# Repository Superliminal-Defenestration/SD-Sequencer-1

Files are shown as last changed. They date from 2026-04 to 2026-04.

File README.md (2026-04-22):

Drum machine / sequencer being developed in Kicad 8. Open source and free to use, based mainly on Roland TR808s, etc.
As simple as it gets--- nothing to produce fancy attack/decay envelopes on most stuff, mostly only fancy VCA envelopes for white-noise based sounds. This is meant to be as easy to understand and low-cost as possible.
I'll be writing in notes as I develop the system on what math I'm using to determine components :).

White noise generation with transistor breakdown accredited to Moritz Klein!

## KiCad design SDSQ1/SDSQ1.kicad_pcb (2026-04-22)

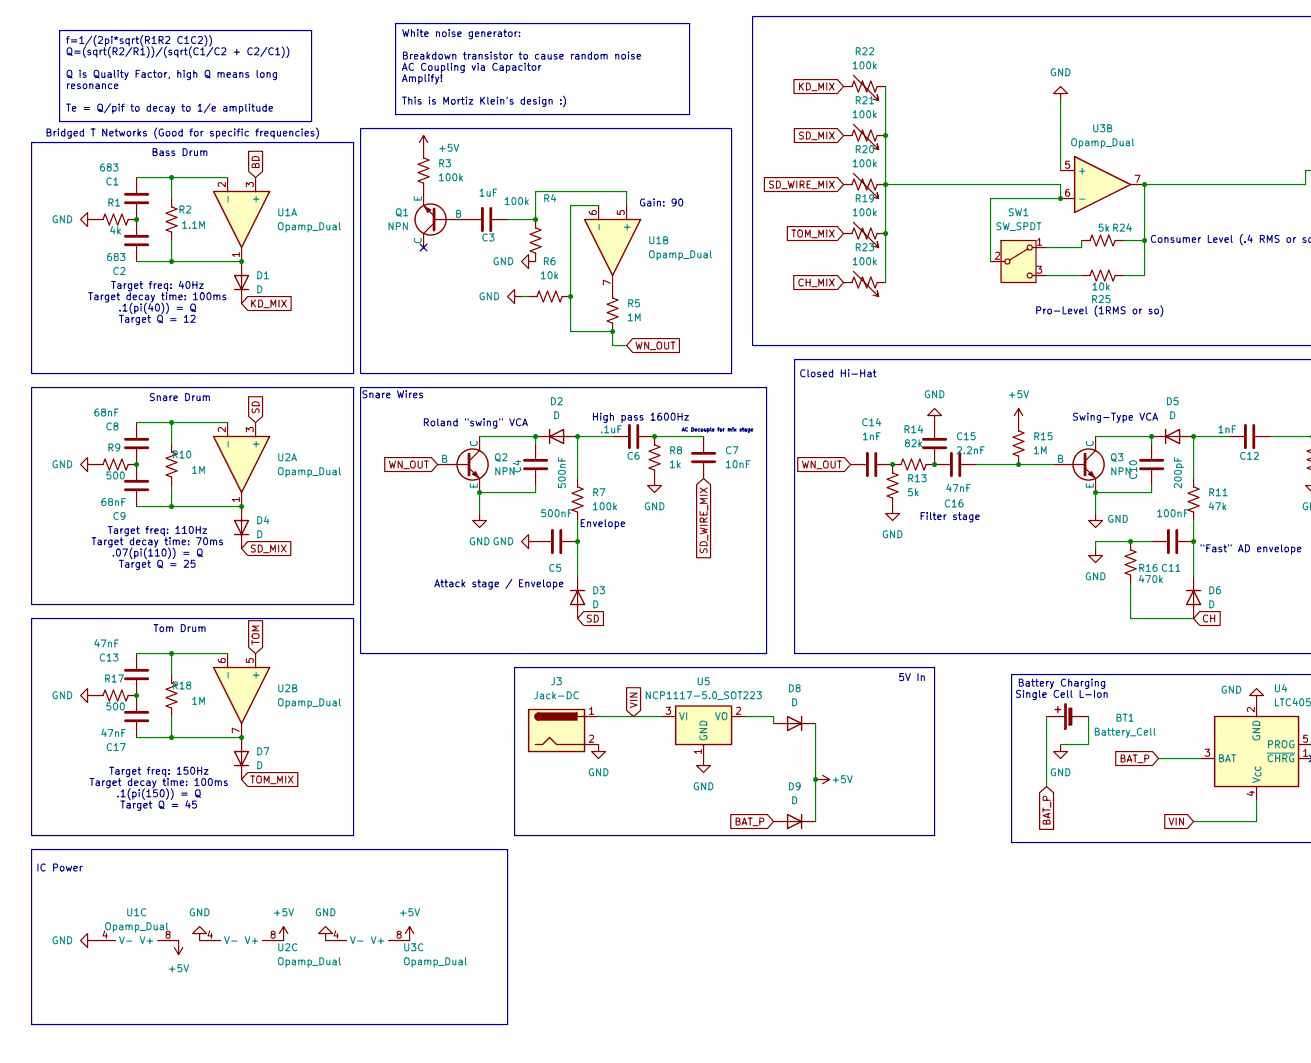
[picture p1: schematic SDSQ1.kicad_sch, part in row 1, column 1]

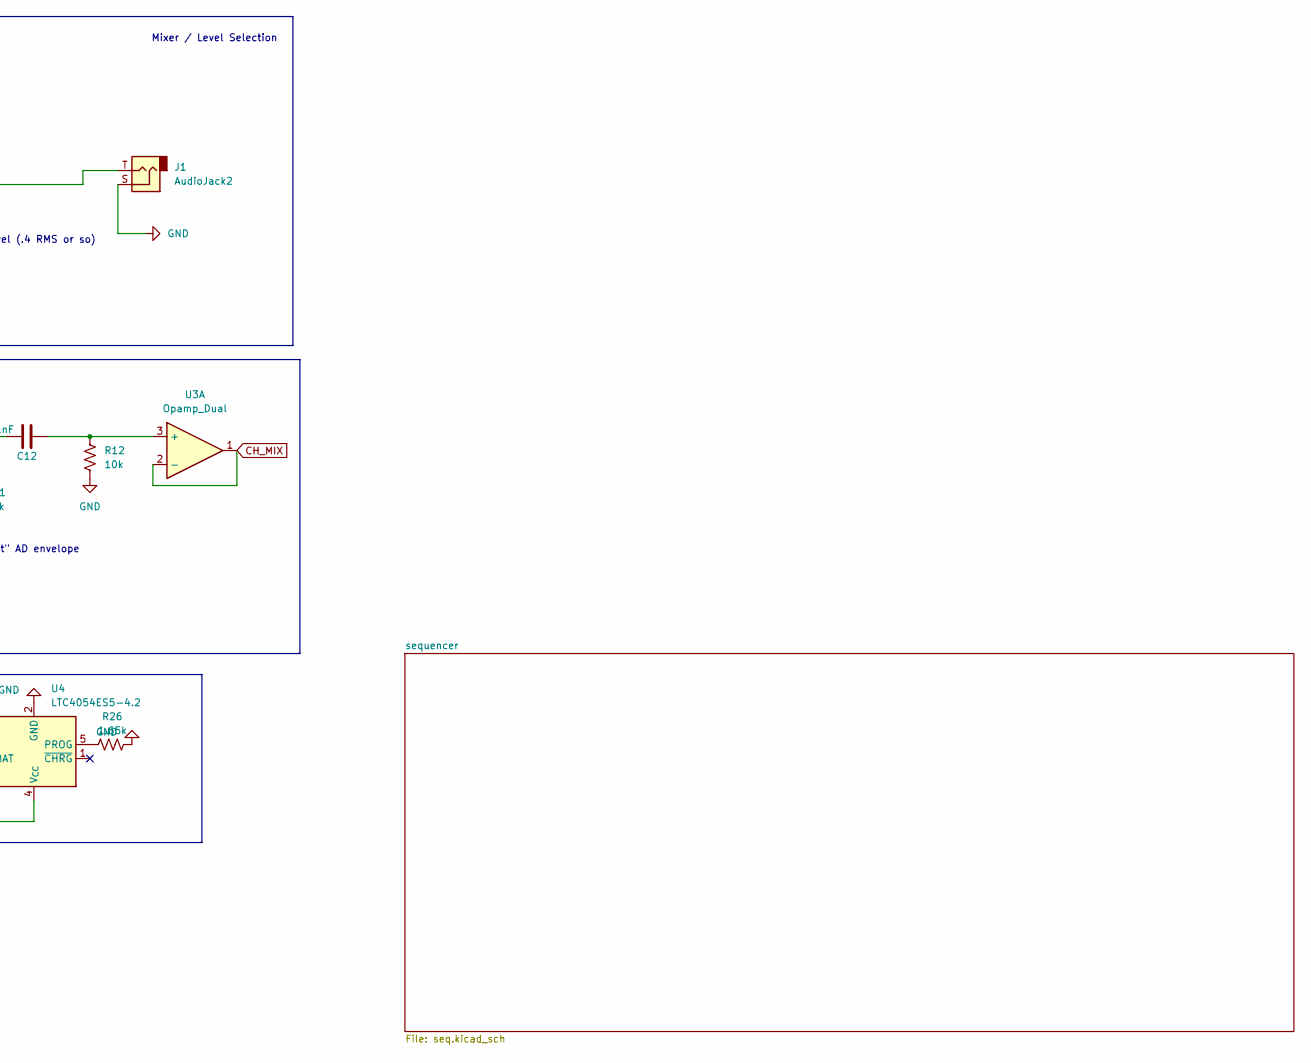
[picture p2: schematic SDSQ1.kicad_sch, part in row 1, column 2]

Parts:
BT1: Battery_Cell; BatteryHolder_Keystone_1042_1x18650
C1, C2: 683; C_Axial_L3.8mm_D2.6mm_P7.50mm_Horizontal
C3: 1uF; C_Axial_L3.8mm_D2.6mm_P7.50mm_Horizontal
C4, C5: 500nF; C_Axial_L3.8mm_D2.6mm_P7.50mm_Horizontal
C6: .1uF; C_Axial_L3.8mm_D2.6mm_P7.50mm_Horizontal
C7: 10nF; C_Axial_L3.8mm_D2.6mm_P7.50mm_Horizontal
C8, C9: 68nF; C_Axial_L3.8mm_D2.6mm_P7.50mm_Horizontal
C10: 200pF; C_Axial_L3.8mm_D2.6mm_P7.50mm_Horizontal
C11: 100nF; C_Axial_L3.8mm_D2.6mm_P7.50mm_Horizontal
C12, C14: 1nF; C_Axial_L3.8mm_D2.6mm_P7.50mm_Horizontal
C13, C16, C17: 47nF; C_Axial_L3.8mm_D2.6mm_P7.50mm_Horizontal
C15: 2.2nF; C_Axial_L3.8mm_D2.6mm_P7.50mm_Horizontal
D1, D2, D3, D4, D5, D6, D7, D8, D9: D; D_A-405_P7.62mm_Horizontal
J1: AudioJack2; Jack_3.5mm_PJ320E_Horizontal
J3: Jack-DC; BarrelJack_Horizontal
Q1, Q2, Q3: NPN; TO-92S
R1: 4k; R_Axial_DIN0204_L3.6mm_D1.6mm_P5.08mm_Vertical
R2: 1.1M; R_Axial_DIN0204_L3.6mm_D1.6mm_P5.08mm_Vertical
R3, R4, R7, R19, R20, R21, R22, R23: 100k; R_Axial_DIN0204_L3.6mm_D1.6mm_P5.08mm_Vertical
R5, R10, R15, R18: 1M; R_Axial_DIN0204_L3.6mm_D1.6mm_P5.08mm_Vertical
R6, R12, R25: 10k; R_Axial_DIN0204_L3.6mm_D1.6mm_P5.08mm_Vertical
R8: 1k; R_Axial_DIN0204_L3.6mm_D1.6mm_P5.08mm_Vertical
R9, R17: 500; R_Axial_DIN0204_L3.6mm_D1.6mm_P5.08mm_Vertical
R11: 47k; R_Axial_DIN0204_L3.6mm_D1.6mm_P5.08mm_Vertical
R13, R24: 5k; R_Axial_DIN0204_L3.6mm_D1.6mm_P5.08mm_Vertical
R14: 82k; R_Axial_DIN0204_L3.6mm_D1.6mm_P5.08mm_Vertical
R16: 470k; R_Axial_DIN0204_L3.6mm_D1.6mm_P5.08mm_Vertical
R26: 1.65k; R_Axial_DIN0204_L3.6mm_D1.6mm_P5.08mm_Vertical
SW1: SW_SPDT; SW_Push_1P2T_Vertical_E-Switch_800UDP8P1A1M6
U1, U2, U3: Opamp_Dual; DIP-8_W7.62mm_Socket
U4: LTC4054ES5-4.2; TSOT-23-5
U5: NCP1117-5.0_SOT223; SOT-223-3_TabPin2

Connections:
+5V: D8.1 (K), D9.1 (K), R3.1, R15.1, U1.8 (V+), U2.8 (V+), U3.8 (V+); also elsewhere on the board
BAT_P: BT1.1 (+), D9.2 (A), U4.3 (BAT)
BD: U1.3 (+); also elsewhere on the board
CH: D6.2 (A), R16.2; also elsewhere on the board
CH_MIX: R23.2, U3.1, U3.2 (-)
GND: BT1.2 (-), C4.2, C5.1, C10.2, C11.1, C15.2, J1.S, J3.2, Q2.3 (E), Q3.3 (E), R1.1, R4.2, R6.1, R8.2, R9.1, R12.2, R13.2, R16.1, R17.1, R26.2, U1.4 (V-), U2.4 (V-), U3.4 (V-), U3.5 (+), U4.2 (GND), U5.1 (GND); also elsewhere on the board
KD_MIX: D1.1 (K), R22.2
unnamed: C1.2, C2.1, R1.2
unnamed: C6.2, C7.2, R8.1
unnamed: C8.2, C9.1, R9.2
unnamed: C13.2, C17.1, R17.2
unnamed: C14.2, R13.1, R14.1
unnamed: C15.1, C16.2, R14.2
unnamed: C2.2, D1.2 (A), R2.1, U1.1
unnamed: C6.1, D2.2 (A), R7.1
unnamed: C4.1, D2.1 (K), Q2.1 (C)
unnamed: C5.2, D3.1 (K), R7.2
unnamed: C9.2, D4.2 (A), R10.1, U2.1
unnamed: C12.1, D5.2 (A), R11.1
unnamed: C10.1, D5.1 (K), Q3.1 (C)
unnamed: C11.2, D6.1 (K), R11.2
unnamed: C17.2, D7.2 (A), R18.1, U2.7
unnamed: D8.2 (A), U5.2 (VO)
unnamed: J1.T, R24.2, R25.2, U3.7
unnamed: C3.1, Q1.2 (B)
unnamed: Q1.3 (E), R3.2
unnamed: C16.1, Q3.2 (B), R15.2
unnamed: R5.1, U1.7
unnamed: R24.1, SW1.1 (A)
unnamed: R19.1, R20.1, R21.1, R22.1, R23.1, SW1.2 (B), U3.6 (-)
unnamed: R25.1, SW1.3 (C)
unnamed: C1.1, R2.2, U1.2 (-)
unnamed: C3.2, R4.1, U1.5 (+)
unnamed: C8.1, R10.2, U2.2 (-)
unnamed: C13.1, R18.2, U2.6 (-)
unnamed: C12.2, R12.1, U3.3 (+)
unnamed: R26.1, U4.5 (PROG)
SD: D3.2 (A), U2.3 (+); also elsewhere on the board
SD_MIX: D4.1 (K), R21.2
SD_WIRE_MIX: C7.1, R20.2
TOM: U2.5 (+); also elsewhere on the board
TOM_MIX: D7.1 (K), R19.2
VIN: J3.1, U4.4 (V_{CC}), U5.3 (VI)
WN_OUT: C14.1, Q2.2 (B), R5.2, R6.2, U1.6 (-)

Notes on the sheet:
White noise generator: Breakdown transistor to cause random noise AC Coupling via Capacitor Amplify! This is Mortiz Klein's design :)
f=1/(2pi*sqrt(R1R2 C1C2)) Q=(sqrt(R2/R1))/(sqrt(C1/C2 + C2/C1)) Q is Quality Factor, high Q means long resonance Te = Q/pif to decay to 1/e amplitude
Envelope
"Fast" AD envelope
Closed Hi-Hat
Swing-Type VCA
AC Decouple for mix stage
5V In
Snare Drum
Bridged T Networks (Good for specific frequencies)
Target freq: 110Hz Target decay time: 70ms .07(pi(110)) = Q Target Q = 25
IC Power
Mixer / Level Selection
Roland "swing" VCA
Tom Drum
Snare Wires
Target freq: 40Hz Target decay time: 100ms .1(pi(40)) = Q Target Q = 12
Battery Charging Single Cell L-Ion
Pro-Level (1RMS or so)
High pass 1600Hz
Consumer Level (.4 RMS or so)
Filter stage
Gain: 90
Bass Drum
Attack stage / Envelope
Target freq: 150Hz Target decay time: 100ms .1(pi(150)) = Q Target Q = 45

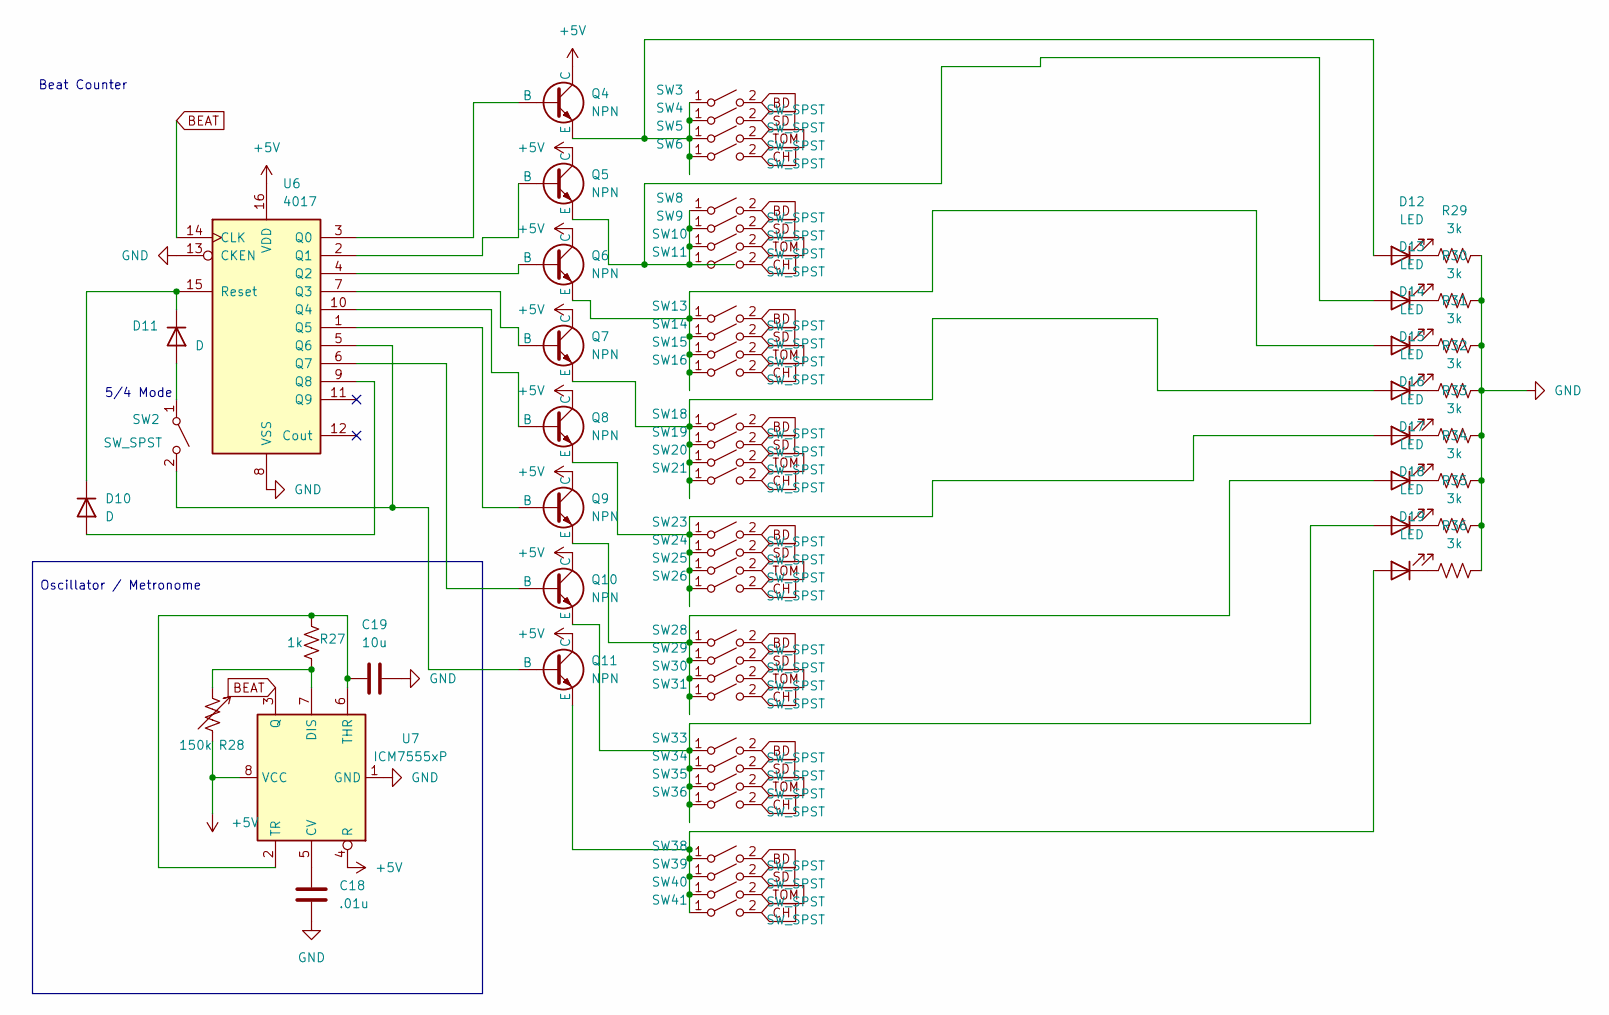
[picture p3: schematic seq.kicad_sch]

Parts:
C18: .01u; C_Axial_L3.8mm_D2.6mm_P7.50mm_Horizontal
C19: 10u; C_Axial_L3.8mm_D2.6mm_P7.50mm_Horizontal
D10, D11: D; D_A-405_P7.62mm_Horizontal
D12, D13, D14, D15, D16, D17, D18, D19: LED; LED_D3.0mm
Q4, Q5, Q6, Q7, Q8, Q9, Q10, Q11: NPN; TO-92
R27: 1k; R_Axial_DIN0204_L3.6mm_D1.6mm_P5.08mm_Vertical
R28: 150k; Potentiometer_Bourns_PTV09A-1_Single_Vertical
R29, R30, R31, R32, R33, R34, R35, R36: 3k; R_Axial_DIN0204_L3.6mm_D1.6mm_P5.08mm_Vertical
SW2, SW3, SW4, SW5, SW6, SW8, SW9, SW10, SW11, SW13, SW14, SW15, SW16, SW18, SW19, SW20, SW21, SW23, SW24, SW25, SW26, SW28, SW29, SW30, SW31, SW33, SW34, SW35, SW36, SW38, SW39, SW40, SW41: SW_SPST; SW_CW_GPTS203211B
U6: 4017; DIP-16_W7.62mm_Socket
U7: ICM7555xP; DIP-8_W7.62mm

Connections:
+5V: Q4.1 (C), Q5.1 (C), Q6.1 (C), Q7.1 (C), Q8.1 (C), Q9.1 (C), Q10.1 (C), Q11.1 (C), R28.2, U6.16 (VDD), U7.4 (R), U7.8 (VCC); also elsewhere on the board
BD: SW3.2 (B), SW8.2 (B), SW13.2 (B), SW18.2 (B), SW23.2 (B), SW28.2 (B), SW33.2 (B), SW38.2 (B); also elsewhere on the board
BEAT: U6.14 (CLK), U7.3 (Q)
CH: SW6.2 (B), SW11.2 (B), SW16.2 (B), SW21.2 (B), SW26.2 (B), SW31.2 (B), SW36.2 (B), SW41.2 (B); also elsewhere on the board
GND: C18.2, C19.1, R29.2, R30.2, R31.2, R32.2, R33.2, R34.2, R35.2, R36.2, U6.8 (VSS), U6.13 (CKEN), U7.1 (GND); also elsewhere on the board
unnamed: D10.2 (A), U6.9 (Q8)
unnamed: D10.1 (K), D11.1 (K), U6.15 (Reset)
unnamed: D11.2 (A), SW2.1 (A)
unnamed: D12.2 (A), Q4.3 (E), SW3.1 (A), SW4.1 (A), SW5.1 (A), SW6.1 (A)
unnamed: D12.1 (K), R29.1
unnamed: D13.2 (A), Q5.3 (E), SW8.1 (A), SW9.1 (A), SW10.1 (A), SW11.1 (A)
unnamed: D13.1 (K), R30.1
unnamed: D14.2 (A), Q6.3 (E), SW13.1 (A), SW14.1 (A), SW15.1 (A), SW16.1 (A)
unnamed: D14.1 (K), R31.1
unnamed: D15.2 (A), Q7.3 (E), SW18.1 (A), SW19.1 (A), SW20.1 (A), SW21.1 (A)
unnamed: D15.1 (K), R32.1
unnamed: D16.2 (A), Q8.3 (E), SW23.1 (A), SW24.1 (A), SW25.1 (A), SW26.1 (A)
unnamed: D16.1 (K), R33.1
unnamed: D17.2 (A), Q9.3 (E), SW28.1 (A), SW29.1 (A), SW30.1 (A), SW31.1 (A)
unnamed: D17.1 (K), R34.1
unnamed: D18.2 (A), Q10.3 (E), SW33.1 (A), SW34.1 (A), SW35.1 (A), SW36.1 (A)
unnamed: D18.1 (K), R35.1
unnamed: D19.2 (A), Q11.3 (E), SW38.1 (A), SW39.1 (A), SW40.1 (A), SW41.1 (A)
unnamed: D19.1 (K), R36.1
unnamed: Q4.2 (B), U6.3 (Q0)
unnamed: Q5.2 (B), U6.2 (Q1)
unnamed: Q6.2 (B), U6.4 (Q2)
unnamed: Q7.2 (B), U6.7 (Q3)
unnamed: Q8.2 (B), U6.10 (Q4)
unnamed: Q9.2 (B), U6.1 (Q5)
unnamed: Q10.2 (B), U6.6 (Q7)
unnamed: Q11.2 (B), SW2.2 (B), U6.5 (Q6)
unnamed: C18.1, U7.5 (CV)
unnamed: R27.1, R28.1, U7.7 (DIS)
unnamed: C19.2, R27.2, U7.2 (TR), U7.6 (THR)
SD: SW4.2 (B), SW9.2 (B), SW14.2 (B), SW19.2 (B), SW24.2 (B), SW29.2 (B), SW34.2 (B), SW39.2 (B); also elsewhere on the board
TOM: SW5.2 (B), SW10.2 (B), SW15.2 (B), SW20.2 (B), SW25.2 (B), SW30.2 (B), SW35.2 (B), SW40.2 (B); also elsewhere on the board

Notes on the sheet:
Beat Counter
Oscillator / Metronome
5/4 Mode

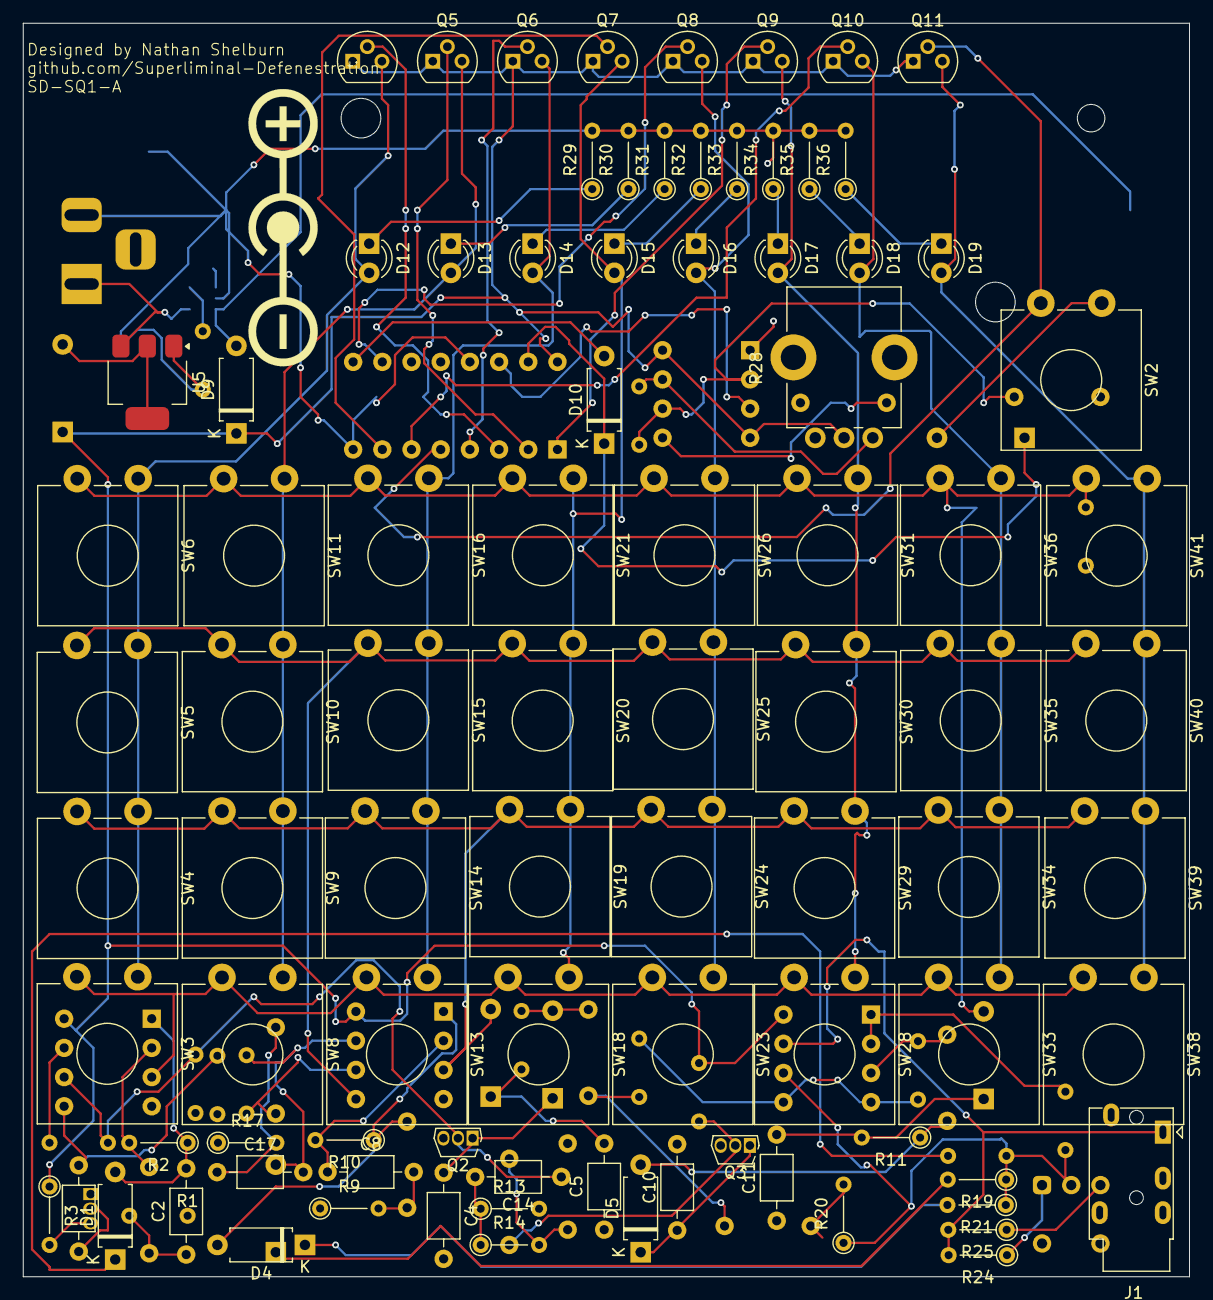
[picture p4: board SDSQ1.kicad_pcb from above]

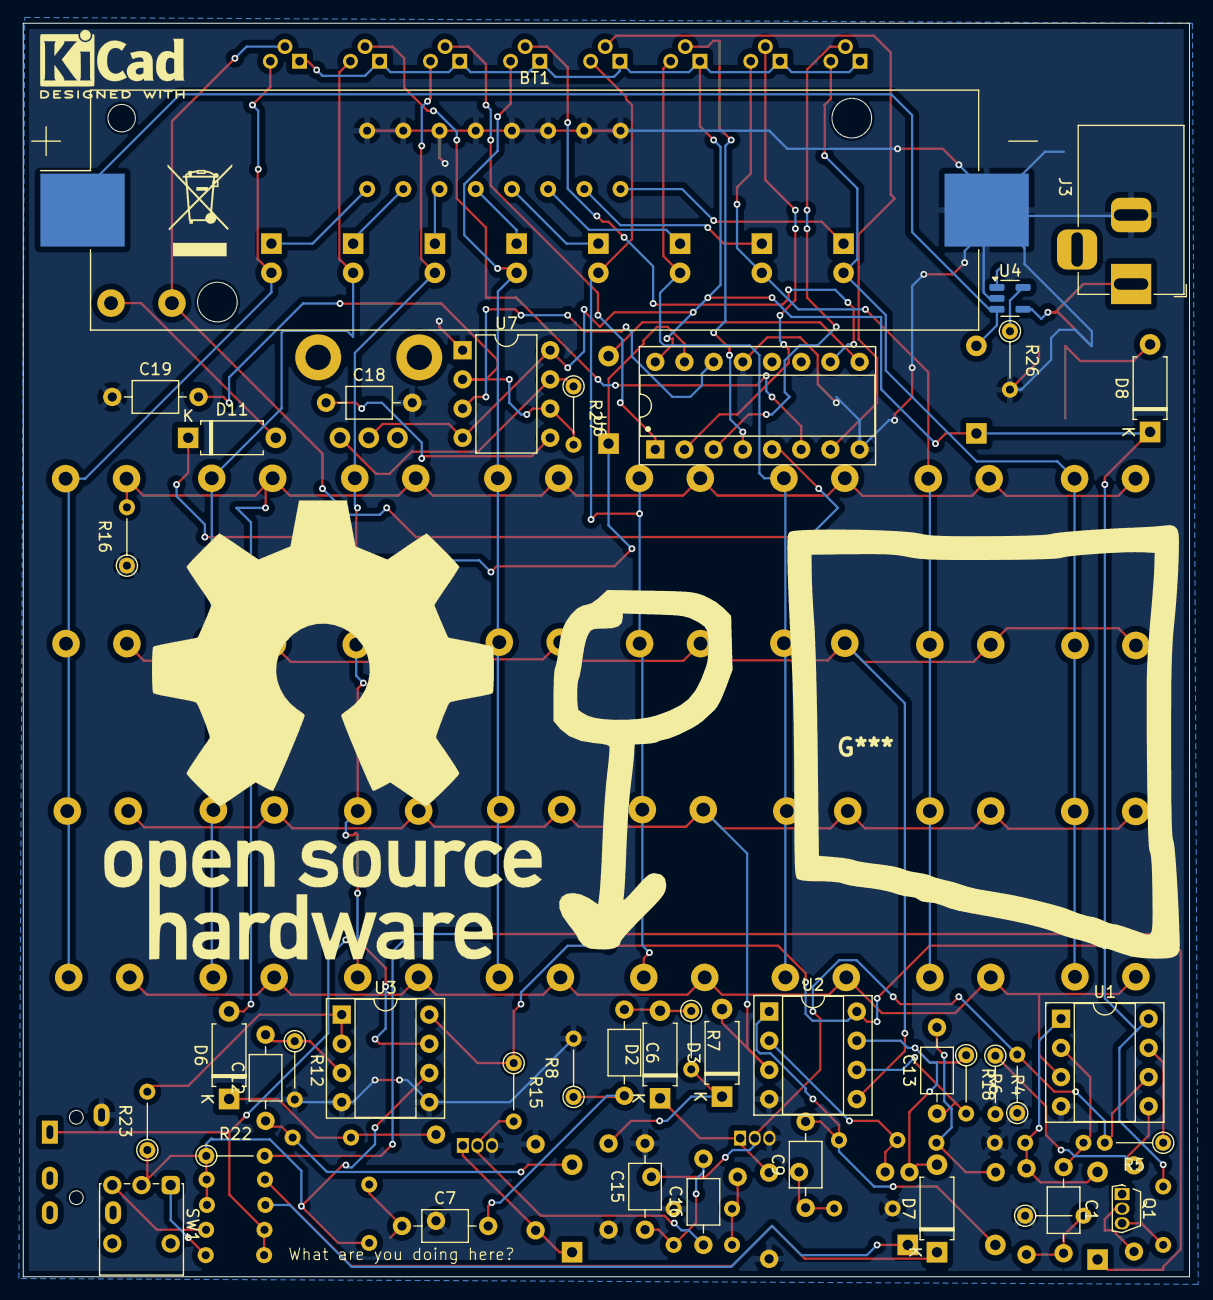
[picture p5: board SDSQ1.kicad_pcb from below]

Board: 2 copper layers, 101.5 x 109.1 mm, 129 parts (40 on the bottom side), 75 nets.

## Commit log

2026-03-13 Added bass and WNG
    [SDSQ1.kicad_pcb, SDSQ1.kicad_sch]
2026-03-18 added snare wire noise
2026-03-18 snare main drum
    [SDSQ1.kicad_sch]
2026-04-16 added hats
    [SDSQ1.kicad_sch]
2026-04-16 added pow management
    [SDSQ1.kicad_sch]
2026-04-22 removed ignores
    [SDSQ1-B_Cu.gbr, SDSQ1-B_Mask.gbr, SDSQ1-B_Paste.gbr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]
